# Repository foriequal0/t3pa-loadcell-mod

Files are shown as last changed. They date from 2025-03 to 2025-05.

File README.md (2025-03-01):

# Thrustmaster T3PA pedal load cell mod without a dead zone

Several prior works[^prior-works-1][^prior-works-2] replaced the existing potentiometer with a load cell. So there should be a physical dead zone until the pedal conacts the load cell, or the pedal's travel distance should be sacrificed by removing the gap.

I've solved the dead zone problem by integrating the existing potentiometer and a load cell.

[^prior-works-1]: [Thrustmaster T3PA Load Cell Mod - Falcon's Tech](https://www.youtube.com/watch?v=KIldeuIU-jM)
[^prior-works-2]: [Thrustmaster t3pa pedal Load Cell Mod | Simonas G](https://slowlogicboy.github.io/electronics/sim%20racing/TM-T3PA-LoadCellMod/)

There are two versions of the load cell mod in this repository.

* [v0](./t3pa-loadcell-mod-v0/README.md) : First prototype that is built by hand-soldering on a prototype board.
* [v1](./t3pa-loadcell-mod-v1/README.md) : It requires PCB manufacturing, but still hand-solderable.

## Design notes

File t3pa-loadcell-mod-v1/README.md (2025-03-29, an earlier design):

# v1

I've designed a PCB for a better design. I've fixed my mistakes.

## Overview

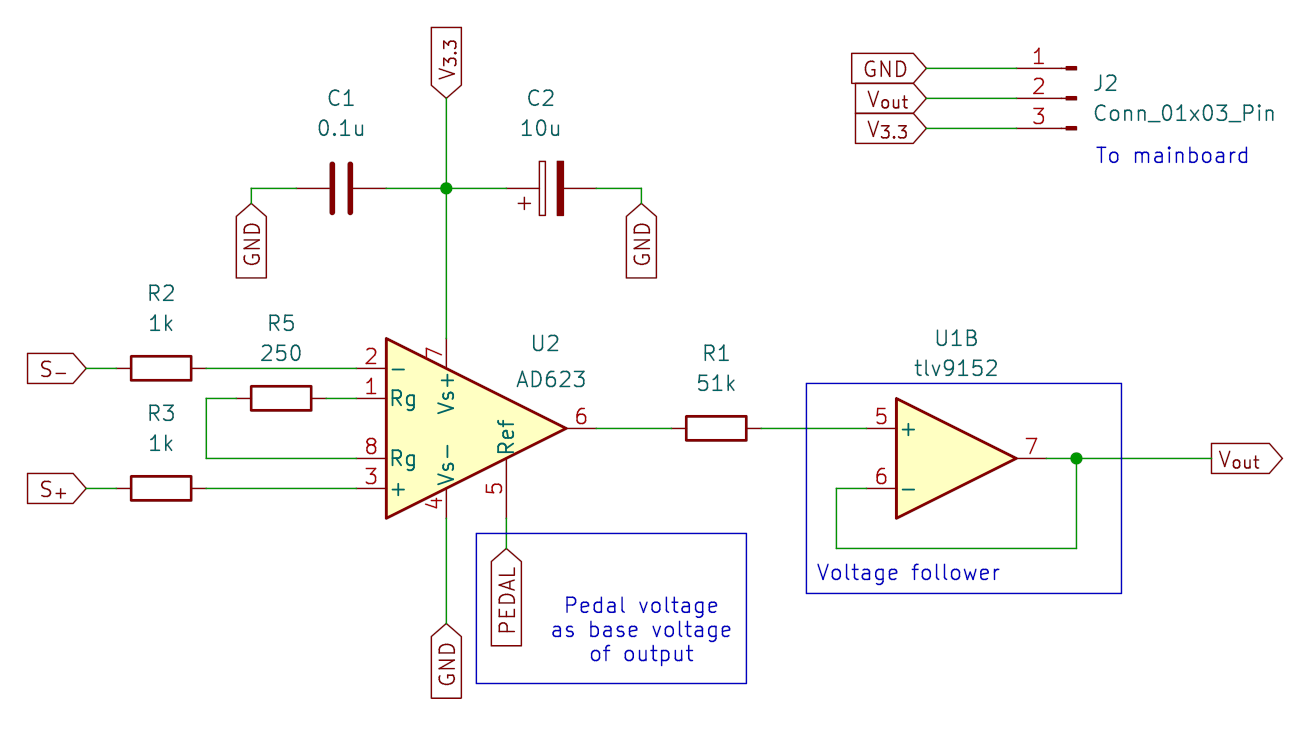
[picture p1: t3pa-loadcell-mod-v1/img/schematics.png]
v1 schematics


The idea is simple: Use amplifier's REF pin to add the pedal's voltage.

## Parts

* Load cell
  * CZL-611P 40kg
  * Wago 233-504, but KF141R would do the job.
* PCB
  * AD623ARMZ
  * TLV9152IPWR
  * 0805 SMD resistors, capacitors, optional tantalum caps.
* 3-pin JST-XH connectors
  * housing: XHP-3
  * header: B3B-XH-A/B3B-XH-AM
* and some mounting hardware
  * M6x2.1x27x35 Compression Spring Seat
  * M6xM10 thread inserts
  * M6x35 bolts, M6 nuts

## Details

Electrical details are the same with [v0](../t3pa-loadcell-mod-v0/README.md).

### PCB

I've used AD620 before, but I've changed it to AD623 which has a rail-to-rail characteristics.
I've chosen 240 Ohm resistor to have 400x gain according to the datasheet.

While skimming through the datasheet, I've noticed Ref pin is used to control the output voltage offset. So I decided to abuse it to add the potentiometer.

I've ordered the PCB from [JLCPCB](https://jlcpcb.com/). Hand-soldering was not that hard.

### Mounting hardware

I've changed conical rubber shock absorber with M6x2.1x27x35 compression spring seat because why not? It can be mounted using M6 bolt. It has the right amount of compression force than the rubber shock absorber. I've removed the cap to reduce the height.

* [M6x2.1x27x35 compression spring seat - AliExpress](https://www.aliexpress.com/item/1005006497936423.html)

The rest is the same with the v0.

## Photos

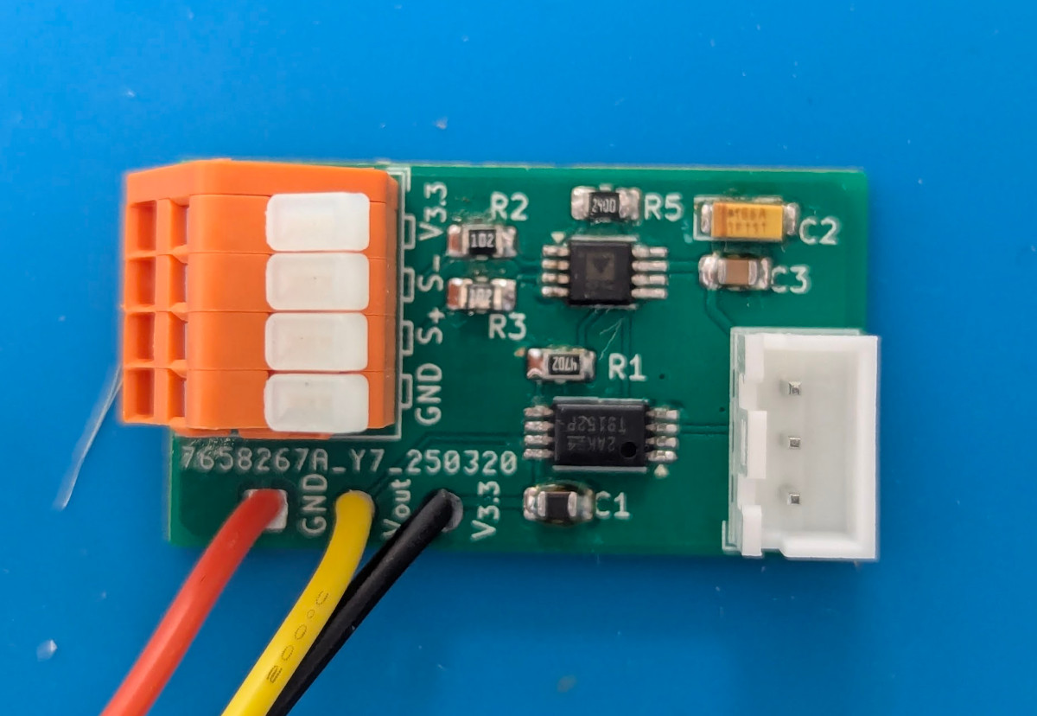
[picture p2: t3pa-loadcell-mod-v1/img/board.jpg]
board from the top
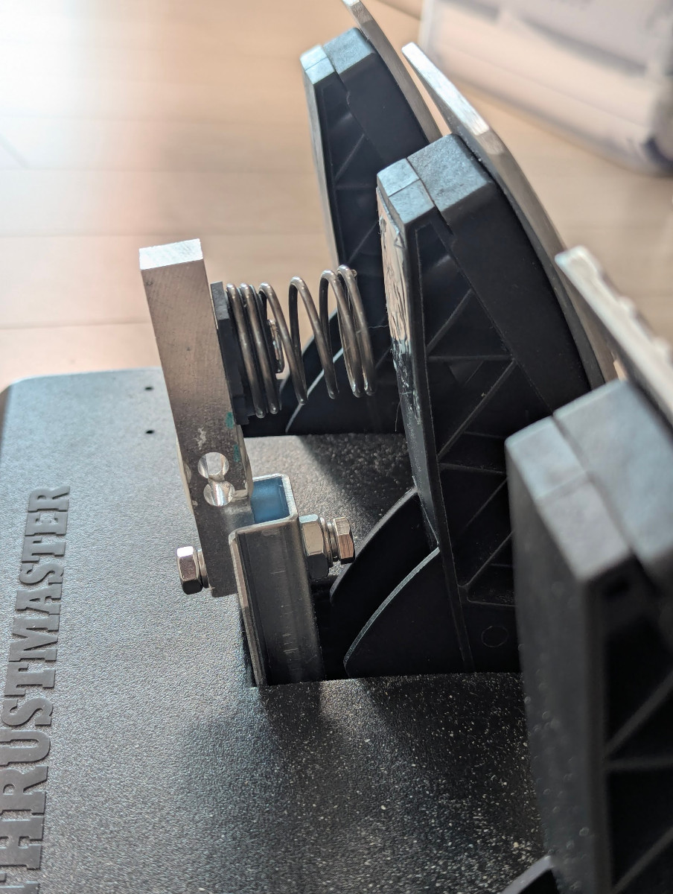
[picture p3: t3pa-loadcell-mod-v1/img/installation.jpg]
load cell installation
 

## Result

Much better than v0. It's smaller, simpler, and less noisy.

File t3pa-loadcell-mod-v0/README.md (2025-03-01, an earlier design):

# v0: A prototype

I've built a prototype on a prototype board with a hand-soldering. I've made some mistakes, but it works fine.
PCB design included in the repo is a replica of the layout of the prototype.

## Overview

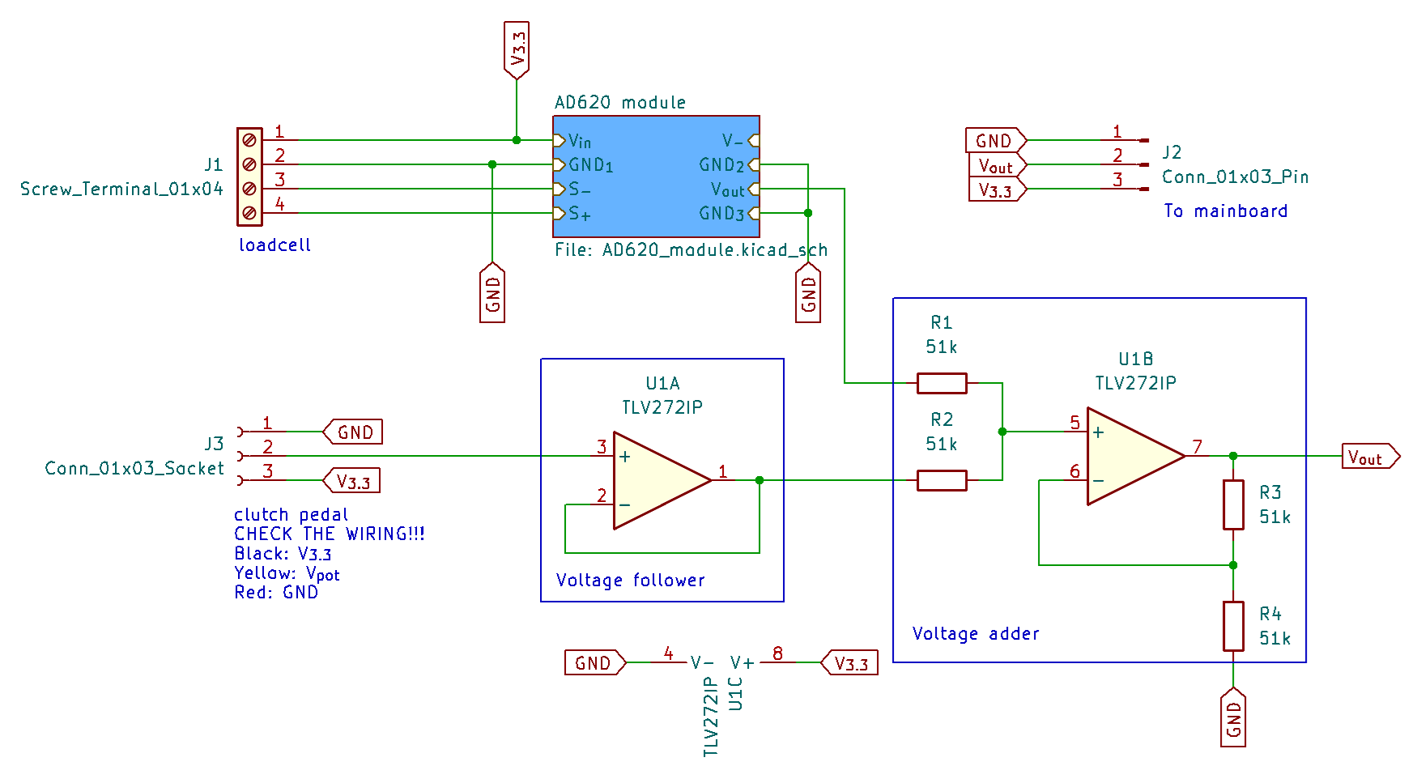
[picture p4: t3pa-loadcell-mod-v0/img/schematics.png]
v0 schematics


The idea is simple: Add voltages from two components with a voltage adder circuit.

## Parts

* Load cell
  * CZL-611P 40kg
  * 4-pin screw terminal block (5mm)
* Load cell amplifier
  * AD620 breakout module
  * 0603 (1608 metric) resistor (100 Ohm)
  * 1x4 female pin header (x2, 2.54mm pitch)
* Voltage adder
  * TLV272IP
  * 4 identical resistors (approx. 50k Ohm, 0.25W)
  * DIP-8 socket
* 3-pin JST-XH connectors
  * housing: XHP-3
  * header: B3B-XH-A/B3B-XH-AM
* and some mounting hardware
  * M6x18X20X25 conical rubber shock absorber
  * M6xM10 thread inserts
  * M6x35 bolts, M6 nuts

## Details

### The existing potentiometer

This is the measurement of potentiometers of mine:

| | Gas | Brake | Clutch |
| --- | ----- | ----- | --- |
| V to GND (Ohm) | 24.8k | 21.9k |  24.0k |
| at rest (Ohm)  | 8.8k  | 12.0k | 9.7k |
| at full (Ohm)  | 24.8k | 21.9k |  24.0k |

I don't know why there are huge differences between the potentiometers, and how the wheel auto-calibrates,
but the important thing is that the voltage doesn't swing a whole range of 0V ~ 3.3V. The brake swings just from 1.8V to 3.3V.
So I have to tune the load cell amplifier to have a range of 1.5V.

Please check the wiring since it doesn't follow normal color codes. Mine was black for 3.3V, red for GND, and yellow for voltage output.

### CZL-611P 40kg

I bought it from [AliExpress](https://ko.aliexpress.com/item/1005007928954675.html). 50kg one arrived (it doesn't matter for the application).

The store page says the output sensitivity is '10 ± 0.1mVN', but I think it is a typo. Some other websites say it is '1.0 ± 0.1mV/V'.
So, the output voltage difference at full load (50kg) will be 3.3mV because the given excitation voltage is 3.3V.
To get an approx. 1.5V output range, we need a gain of approx. 450x.
If we need an output range of 1.3V, the gain will be approx. 400x.

I've cut the first screw hole part out with a hand saw to reduce interference when installing.

### AD620 breakout module

I've bought AD620 breakout modules by mistake instead of AD623. I didn't know its limited output range (V_in - 2.0V).
Luckily ~1.3V range is somewhat enough for this project (the first 0.2V range will be covered by the potentiometer)

You can buy it and get more information about it from [Proto Supplies](https://protosupplies.com/product/ad620-instrumentation-amplifier-module/).
Or you could get cheaper clones from AliExpress instead. It seems that there are several versions of it on Aliexpress. The module's dimension that I've used is 32mm * 22mm.

To get a gain of 400x, I've changed its 100K trimmer potentiometer with a fixed 120 Ohm resistor by following the Proto Supplies' guide (R_gain = 49.9K / (Gain -1).
After that, I adjusted the zero offset with the load cell connected.

You shouldn't remove 7660 since it seems necessary to our application's range.

### TLV272IP

I bought LM358 at first because AD620 module used it, and I discovered that it heavily clips the output voltage (maximum output is approx. 2.0V out of 3.3V) too late.
It might be the reason why AD620 breakout module's range is limited and it needs 7660!
Luckily, I found a StackExchange answer that suggested a rail-to-rail op-amp such as TLV27x series[^stackexchange].
It is pin-to-pin compatible with LM358, so I've bought TLV272IP.
It was a good idea to use DIP-8 socket instead of directly soldering LM358 to the board.

[^stackexchange]: https://electronics.stackexchange.com/a/357054

Exact resistor values don't matter unless they are large (10k~100k Ohm), and relatively equal to each other (R1 = R2, R3 = R4). I've actually picked R1 = R2 = 51k, R3 = R4 = 47k.

### Mounting hardware

I bought M6x18X20X25 conical rubber shock absorber because CZL-611P has M6 threaded holes.

* [M6x18X20X25 - AliExpress](https://www.aliexpress.com/item/1005005386072058.html)

I've used a M6xM10 threaded insert since T3PA's bracket has M10 threaded hole while CZL-611P has M6 threaded hole. I bought 10mm length one, but 12mm or 15mm one would've been nicer to work with.
A M10 nut that is included in T3PA's bracket mod kit is used to lock the threaded insert to the bracket.
M6x35 bolt, M6 nuts to mount CZL-611 onto the bracket.

* [M6xM10 threaded insert - AliExpress](https://www.aliexpress.com/item/1005006827476112.html)

## Photos

Here are some photos of the prototype board.

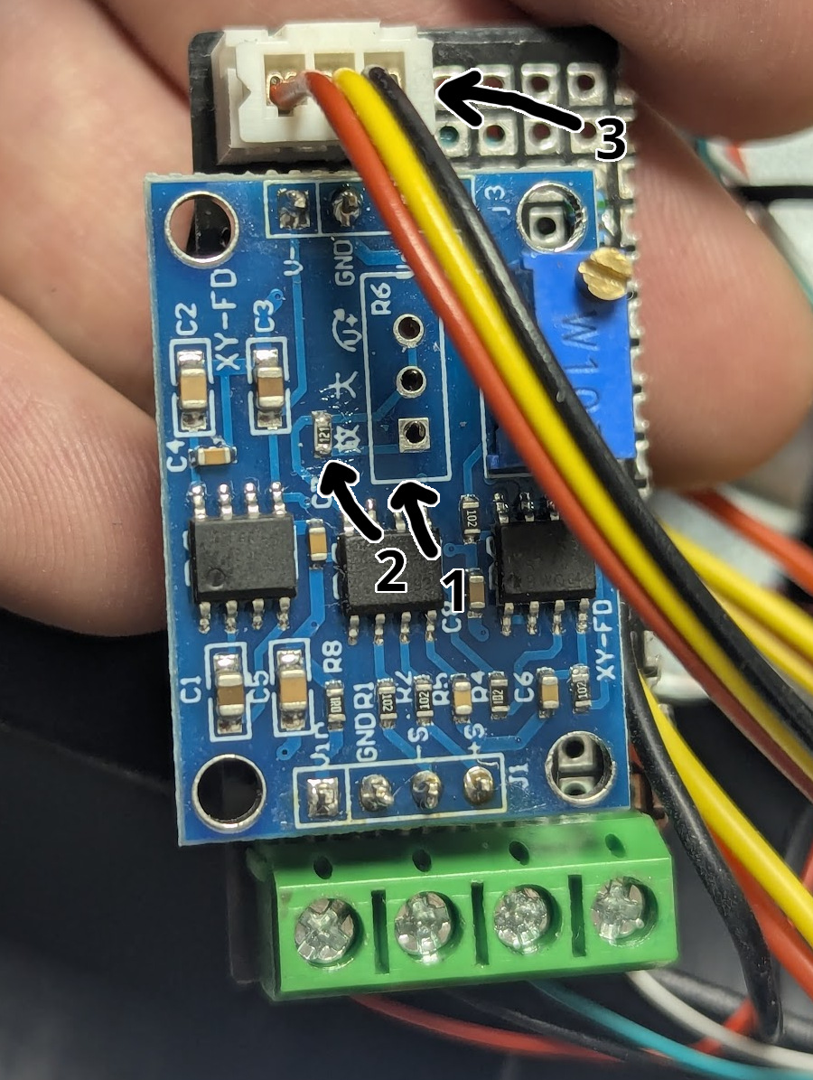
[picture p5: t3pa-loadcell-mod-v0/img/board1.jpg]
board from the top
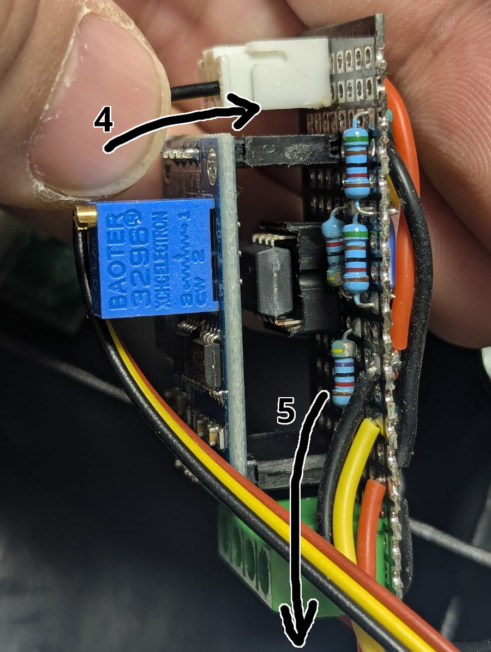
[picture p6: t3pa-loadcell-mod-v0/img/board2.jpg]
board from the side
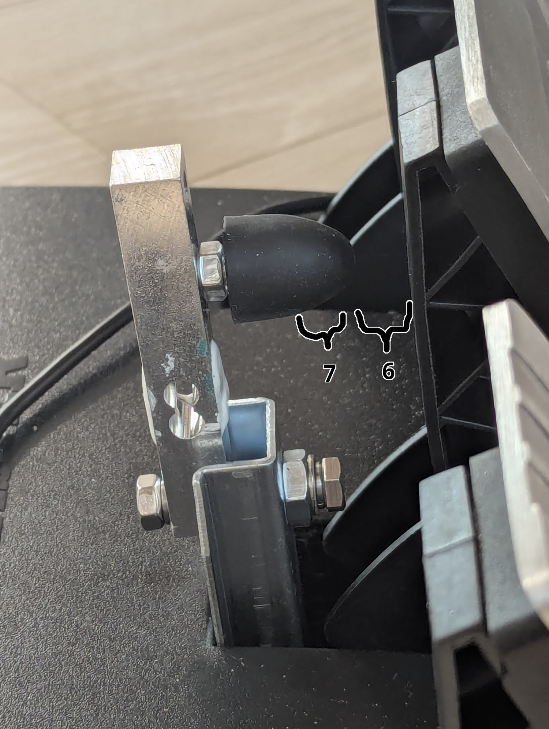
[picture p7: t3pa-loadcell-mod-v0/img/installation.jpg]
load cell installation
  

1. Removed gain trimmer potentiometer.
2. Installed 120 Ohm resistor (metric 1608, imperial 0603)
3. The connector from the existing potentiometer. Don't be fooled by wiring colors.
4. From the potentiometer.
5. To the mainboard of the pedal.
6. The range that is covered by the potentiometer.
7. The range that is covered by the load cell.

## Result

You can control the brakes delicately as you could before in the potentiometer range.
In the load cell range, you can feel the physical resistance when you hit the brakes hard while not losing controllability.
The transition between the potentiometer and the load cell is smooth as expected although the output is a little bit noisier than before.

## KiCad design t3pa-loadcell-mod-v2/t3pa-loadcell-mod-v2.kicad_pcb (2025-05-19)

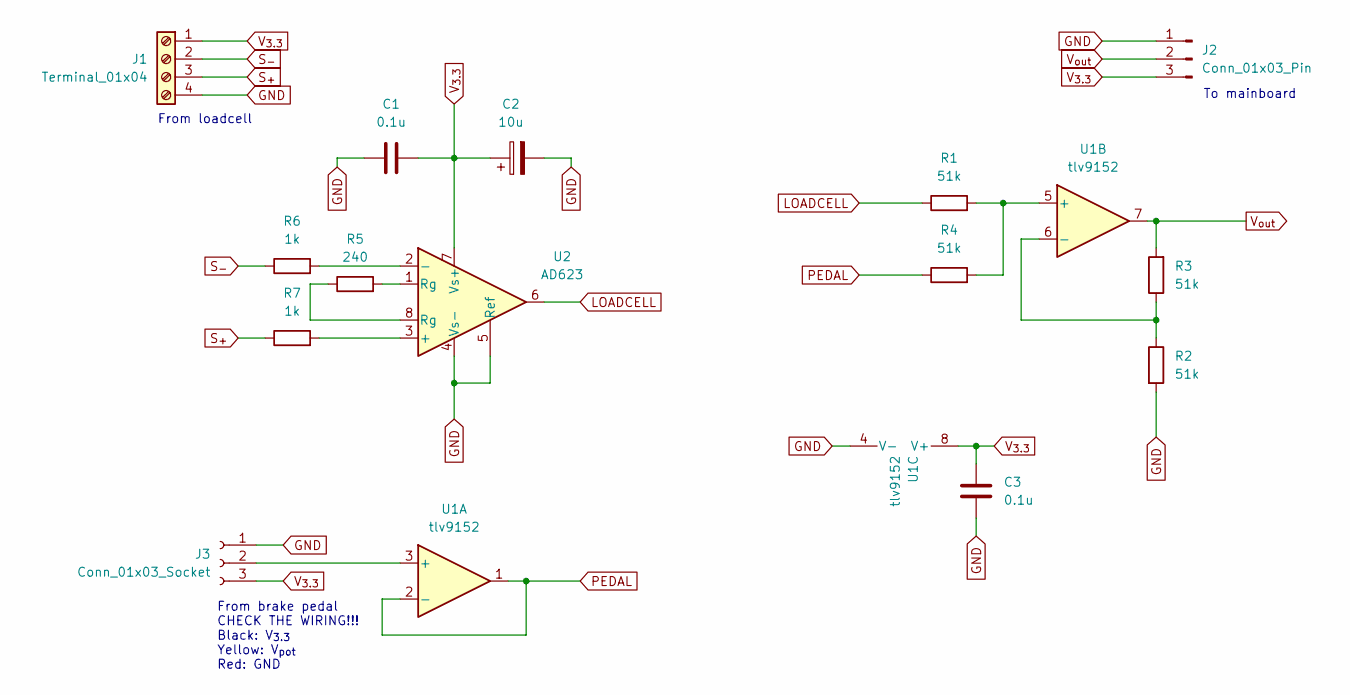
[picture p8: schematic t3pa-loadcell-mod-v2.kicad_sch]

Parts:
C1, C3: 0.1u; C_0805_2012Metric_Pad1.18x1.45mm_HandSolder
C2: 10u; CP_EIA-3216-10_Kemet-I_Pad1.58x1.35mm_HandSolder
J1: Terminal_01x04; TerminalBlock_WAGO_233-504_2x04_P2.54mm
J2: Conn_01x03_Pin; SolderWire-0.25sqmm_1x03_P4.2mm_D0.65mm_OD1.7mm
J3: Conn_01x03_Socket; JST_XH_B3B-XH-A_1x03_P2.50mm_Vertical
R1, R2, R3, R4: 51k; R_0805_2012Metric_Pad1.20x1.40mm_HandSolder
R5: 240; R_0805_2012Metric_Pad1.20x1.40mm_HandSolder
R6, R7: 1k; R_0805_2012Metric_Pad1.20x1.40mm_HandSolder
U1: tlv9152; TSSOP-8_4.4x3mm_P0.65mm
U2: AD623; MSOP-8_3x3mm_P0.65mm

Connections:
GND: C1.1, C2.2, C3.2, J1.4, J2.1, J3.1, R2.2, U1.4 (V-), U2.4 (Vs-), U2.5 (Ref)
LOADCELL: R1.1, U2.6
unnamed: J3.2, U1.3 (+)
unnamed: R5.1, U2.8 (Rg)
unnamed: R5.2, U2.1 (Rg)
unnamed: R1.2, R4.2, U1.5 (+)
unnamed: R2.1, R3.1, U1.6 (-)
unnamed: R7.2, U2.3 (+)
unnamed: R6.2, U2.2 (-)
PEDAL: R4.1, U1.1, U1.2 (-)
S_{+}: J1.3, R7.1
S_{-}: J1.2, R6.1
V_{3.3}: C1.2, C2.1, C3.1, J1.1, J2.3, J3.3, U1.8 (V+), U2.7 (Vs+)
V_{out}: J2.2, R3.2, U1.7

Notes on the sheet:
To mainboard
From loadcell
From brake pedal CHECK THE WIRING!!! Black: V_{3.3} Yellow: V_{pot} Red: GND

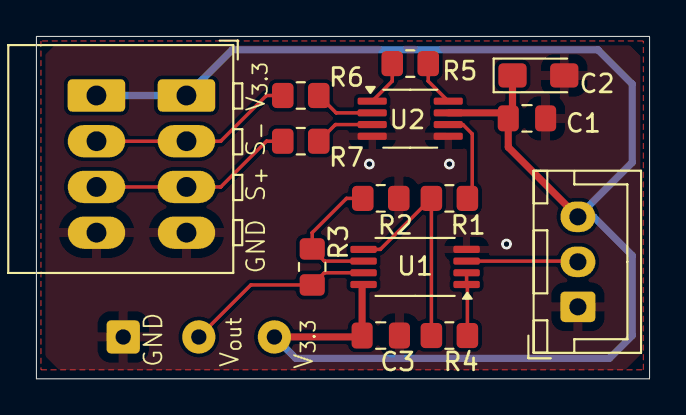
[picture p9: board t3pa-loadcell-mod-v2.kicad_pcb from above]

Board: 2 copper layers, 34.1 x 19.0 mm, 15 parts (0 on the bottom side), 14 nets.

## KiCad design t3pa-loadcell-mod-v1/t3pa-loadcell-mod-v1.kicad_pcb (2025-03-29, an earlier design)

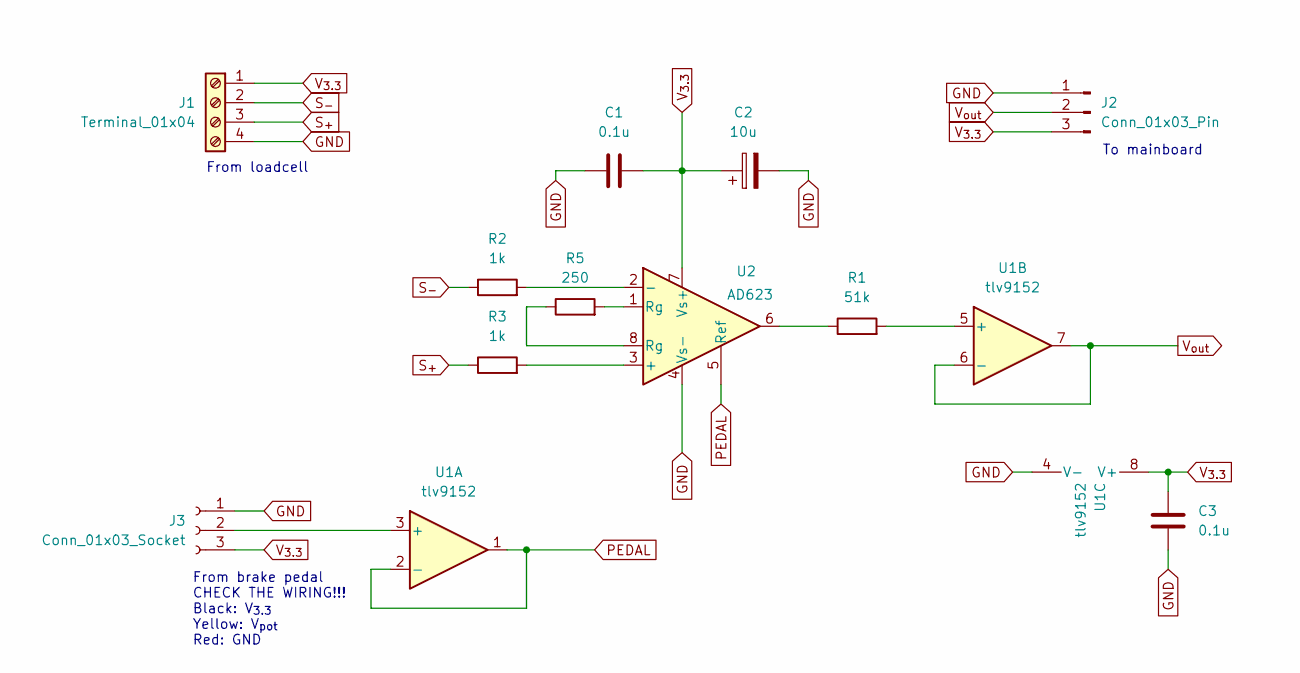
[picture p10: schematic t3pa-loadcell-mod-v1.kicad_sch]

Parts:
C1, C3: 0.1u; C_0805_2012Metric_Pad1.18x1.45mm_HandSolder
C2: 10u; CP_EIA-3216-10_Kemet-I_Pad1.58x1.35mm_HandSolder
J1: Terminal_01x04; TerminalBlock_WAGO_233-504_2x04_P2.54mm
J2: Conn_01x03_Pin; SolderWire-0.25sqmm_1x03_P4.2mm_D0.65mm_OD1.7mm
J3: Conn_01x03_Socket; JST_XH_B3B-XH-A_1x03_P2.50mm_Vertical
R1: 51k; R_0805_2012Metric_Pad1.20x1.40mm_HandSolder
R2, R3: 1k; R_0805_2012Metric_Pad1.20x1.40mm_HandSolder
R5: 250; R_0805_2012Metric_Pad1.20x1.40mm_HandSolder
U1: tlv9152; TSSOP-8_4.4x3mm_P0.65mm
U2: AD623; MSOP-8_3x3mm_P0.65mm

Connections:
GND: C1.1, C2.2, C3.2, J1.4, J2.1, J3.1, U1.4 (V-), U2.4 (Vs-)
unnamed: J3.2, U1.3 (+)
unnamed: R1.1, U2.6
unnamed: R5.1, U2.8 (Rg)
unnamed: R5.2, U2.1 (Rg)
unnamed: U1.1, U1.2 (-), U2.5 (Ref)
unnamed: R1.2, U1.5 (+)
unnamed: R3.2, U2.3 (+)
unnamed: R2.2, U2.2 (-)
S_{+}: J1.3, R3.1
S_{-}: J1.2, R2.1
V_{3.3}: C1.2, C2.1, C3.1, J1.1, J2.3, J3.3, U1.8 (V+), U2.7 (Vs+)
V_{out}: J2.2, U1.6 (-), U1.7

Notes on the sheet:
To mainboard
From loadcell
From brake pedal CHECK THE WIRING!!! Black: V_{3.3} Yellow: V_{pot} Red: GND

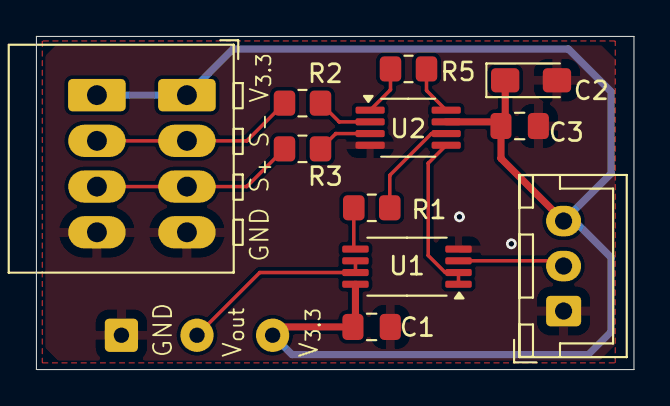
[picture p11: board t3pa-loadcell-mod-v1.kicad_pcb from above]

Board: 2 copper layers, 33.2 x 18.5 mm, 12 parts (0 on the bottom side), 13 nets.

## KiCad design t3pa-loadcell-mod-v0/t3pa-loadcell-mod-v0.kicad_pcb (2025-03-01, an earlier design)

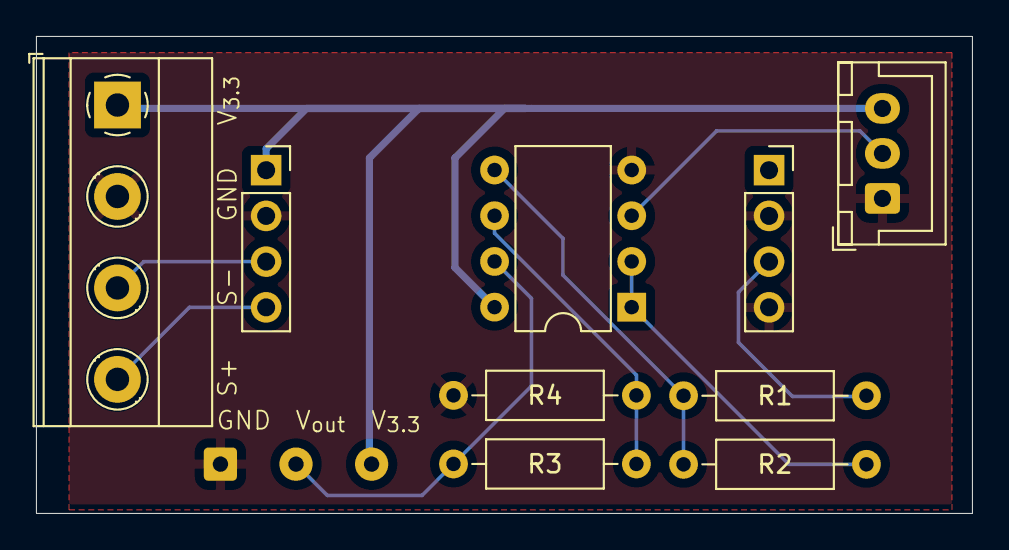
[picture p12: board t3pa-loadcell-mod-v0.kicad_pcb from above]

Board: 2 copper layers, 52.0 x 26.5 mm, 10 parts (0 on the bottom side), 10 nets.

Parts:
J1: Screw_Terminal_01x04; TerminalBlock_Phoenix_MKDS-1,5-4-5.08_1x04_P5.08mm_Horizont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
J2: Conn_01x03_Pin; SolderWire-0.25sqmm_1x03_P4.2mm_D0.65mm_OD1.7mm
J3: Conn_01x03_Socket; JST_XH_B3B-XH-A_1x03_P2.50mm_Vertical
J4, J5: Conn_01x04_Pin; PinSocket_1x04_P2.54mm_Vertical
R1, R2, R3, R4: 51k; R_Axial_DIN0207_L6.3mm_D2.5mm_P10.16mm_Horizontal
U1: TLV272IP; DIP-8_W7.62mm

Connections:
/AD620 module/S_{+}: J1.4, J4.4
/AD620 module/S_{-}: J1.3, J4.3
/AD620 module/V_{out}: J5.3, R1.1
GND: J1.2, J2.1, J3.1, J4.2, J5.2, J5.4, R4.1, U1.4 (V-)
unnamed: J3.2, U1.3 (+)
unnamed: R2.2, U1.1, U1.2 (-)
unnamed: R1.2, R2.1, U1.5 (+)
unnamed: R3.1, R4.2, U1.6 (-)
V_{3.3}: J1.1, J2.3, J3.3, J4.1, U1.8 (V+)
V_{out}: J2.2, R3.2, U1.7

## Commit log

2025-03-01 Update v0
    [AD620_module.kicad_sch, t3pa-loadcell-mod-v0.kicad_pcb, t3pa-loadcell-mod-v0.kicad_sch]
2025-03-29 Update v1
    [t3pa-loadcell-mod-v1.kicad_pcb, t3pa-loadcell-mod-v1.kicad_sch]
2025-05-19 Add v1-alt
    [t3pa-loadcell-mod-v2.kicad_pcb, t3pa-loadcell-mod-v2.kicad_sch]
